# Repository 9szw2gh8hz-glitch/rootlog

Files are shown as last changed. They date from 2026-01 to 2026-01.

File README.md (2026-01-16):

# rootlog
## The Privacy-First, Local Data Logging Solution

RootLog is a dedicated environmental monitoring system designed to put data ownership back into the hands of the user. Unlike cloud-based smart home sensors, RootLog operates 100% locally. It monitors ambient conditions and air quality, storing every data point on a MicroSD card for private analysis.
Project Description

    Privacy-Focused: No Wi-Fi required; no data ever leaves the device.

    Robust Logging: Saves data to a MicroSD card every 60 seconds.

    Data Integrity: Features a "Flush" strategy that physically saves data to the card every 5 minutes to prevent loss during power failure.

    Power Management: Supports a Deep Sleep mode (activated by a 2-second button hold) to conserve battery during portable use.

    Multi-View Display: A 0.91" OLED screen cycles through 4 distinct data pages with a single tap.

## BOM

    Microcontroller: ESP32-C3 SuperMini

    Environmental Sensor: BME280 (Temp, Hum, Pres)

    Air Quality Sensor: SGP30 (eCO2, TVOC)

    Real-Time Clock: DS3231 RTC

    Display: 0.91" I2C OLED (128x32)

    Storage: MicroSD Card Module

## Wiring Map

Component	Pin Function	ESP32-C3 Pin
I2C Bus	SDA	GPIO 8
I2C Bus	SCL	GPIO 9
MicroSD	CS (Chip Select)	GPIO 7
MicroSD	MOSI	GPIO 6
MicroSD	MISO	GPIO 5
MicroSD	SCK (Clock)	GPIO 4
Control	Push Button	GPIO 2
Software & Setup
Required Libraries

## Usage Instructions

    Boot: Upon power-up, the OLED will display "ROOTLOG BOOTING..." while initializing sensors.

    Cycle Pages: Short-press the button to cycle between:

        Temperature (°C)

        Humidity (%) and Pressure (hPa)

        Air Quality (eCO2 ppm and TVOC ppb)

        Current System Time

    Power Off: Hold the button for 2 seconds. The screen will show "BYE BYE" and enter deep sleep.

    Wake Up: Press the button again to resume logging.

    Note on Calibration: The SGP30 air quality sensor requires approximately 15 seconds of operation to stabilize its internal baseline before reporting accurate eCO2 and TVOC values.

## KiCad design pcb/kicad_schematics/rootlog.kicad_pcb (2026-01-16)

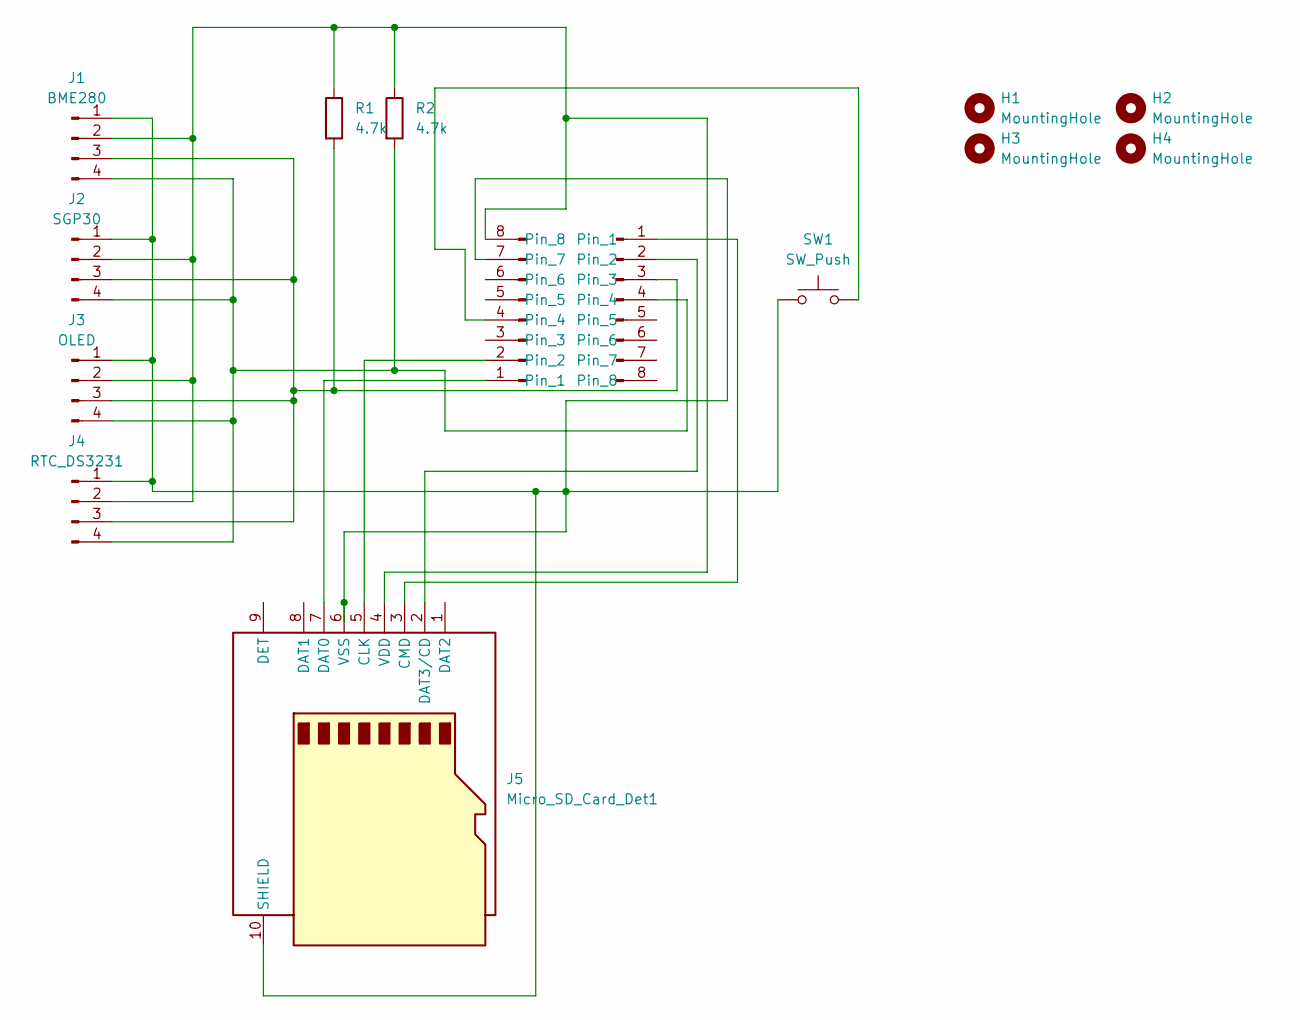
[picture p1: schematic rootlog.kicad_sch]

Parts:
H1, H2, H3, H4: MountingHole; MountingHole_3.2mm_M3
J1: BME280; FanPinHeader_1x04_P2.54mm_Vertical
J2: SGP30; FanPinHeader_1x04_P2.54mm_Vertical
J3: OLED; FanPinHeader_1x04_P2.54mm_Vertical
J4: RTC_DS3231; FanPinHeader_1x04_P2.54mm_Vertical
J5: Micro_SD_Card_Det1; microSD_HC_Hirose_DM3D-SF
J6, J7: Conn_01x08_Pin; PinHeader_1x08_P2.54mm_Vertical
R1, R2: 4.7k; R_Axial_DIN0207_L6.3mm_D2.5mm_P2.54mm_Vertical
SW1: SW_Push; SW_PUSH_6mm_H4.3mm

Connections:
unnamed: J1.1, J2.1, J3.1, J4.1, J5.6 (VSS), J5.10 (SHIELD), J6.7, SW1.1
unnamed: J1.2, J2.2, J3.2, J4.2, J5.4 (VDD), J6.8, R1.1, R2.1
unnamed: J1.3, J2.3, J3.3, J4.3, J7.3, R1.2
unnamed: J1.4, J2.4, J3.4, J4.4, J7.4, R2.2
unnamed: J5.5 (CLK), J6.2
unnamed: J5.3 (CMD), J7.1
unnamed: J5.7 (DAT0), J6.1
unnamed: J5.2 (DAT3/CD), J7.2
unnamed: J6.4, SW1.2

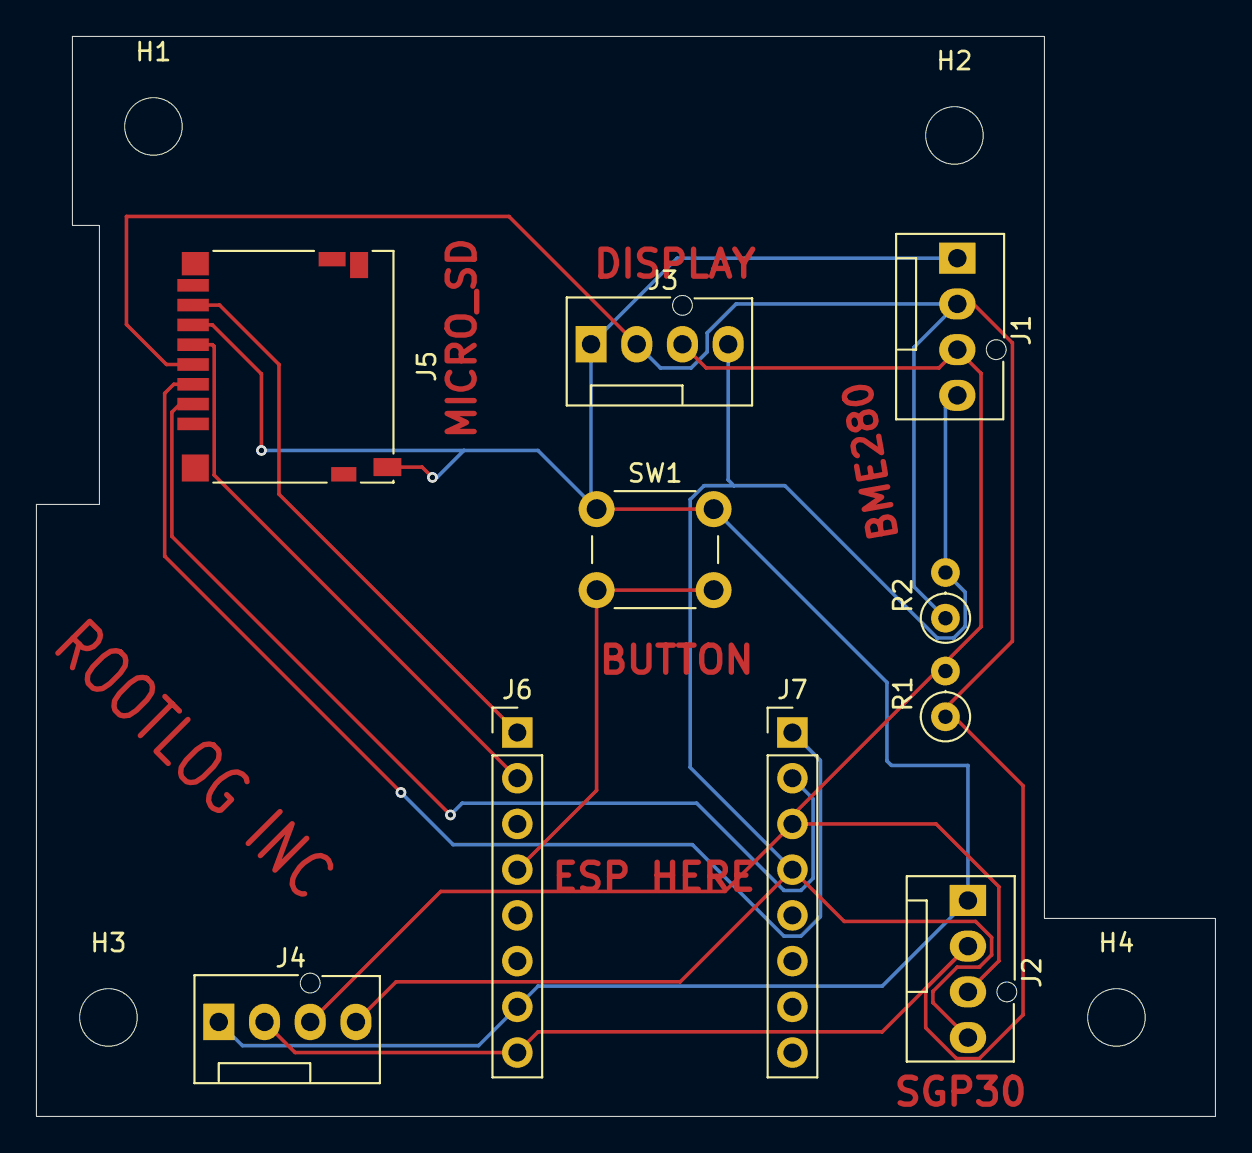
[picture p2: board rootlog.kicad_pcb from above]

Board: 2 copper layers, 65.5 x 60.0 mm, 14 parts (0 on the bottom side), 9 nets.

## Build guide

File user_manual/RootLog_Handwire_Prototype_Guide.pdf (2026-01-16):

RootLog Inc. — Built by hand. Powered by data.

# RootLog Handwire Assembly Guide

Prototype Edition — Point-to-Point Wiring

This guide covers manual assembly of the RootLog using perfboard and hand wiring. It is intended for prototype validation and one-off builds before custom PCB availability.

## Bill of Materials

1 ESP32-C3 SuperMini Microcontroller
2 Perfboard / Prototyping Board (≈4×6 cm)

3 BME280 Sensor Module

4 SGP30 Air Quality Sensor

5 DS3231 RTC Module

6 0.91" OLED Display (I2C)

7 MicroSD Card Module (SPI)

8 Push Button (Tactile)
9 2 × 4.7 kΩ Resistors (I2C Pull-ups)

10 22–24 AWG Solid Core Wire (Color-coded)

## Master Wiring Map

All connections follow a shared Power Bus (3.3 V), Ground Bus, I2C Data Bus, and a dedicated SPI bus for the MicroSD card. GPIO assignments must match firmware configuration.

## Assembly Phases

Phase 1 — Placement: Position the ESP32 near the USB edge. Keep the BME280 distant from the ESP32 to minimize heat influence.
Phase 2 — Power Bus: Create shared 3.3 V and GND rails. Verify continuity across all modules. Phase 3 — I2C Bus: Daisy-chain SDA and SCL, then add 4.7 kΩ pull-up resistors to 3.3 V.
Phase 4 — SPI (MicroSD): Wire CS, MOSI, MISO, and SCK directly to the ESP32 with short leads. Phase 5 — Button: Connect GPIO 2 to GND using the tactile switch; rely on internal pull-up.

## Final Verification & Power-Up

Before applying power, perform continuity checks between 3.3 V and GND. Any short must be corrected before connecting USB. A stable ESP32 LED indicates a safe power state.

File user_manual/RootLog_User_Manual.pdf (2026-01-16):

RootLog Inc. — Privacy First. Data Always.

# RootLog Owner’s Manual

Private Environmental Logger

Welcome to RootLog. You now own a dedicated, privacy■focused environmental monitor. Unlike smart home devices that send your data to the cloud, RootLog keeps everything local. All measurements are stored securely on a MicroSD card for your eyes only.

## What RootLog Monitors

1 Temperature (°C): Precision thermal monitoring.

2 Humidity (%): Relative humidity for comfort and mold prevention.

3 Pressure (hPa): Barometric pressure readings.

4 Air Quality (eCO2 & TVOC): Indicates when ventilation is recommended.

## Getting Started

Step 1: MicroSD Card
Format a MicroSD card to FAT32 and insert it into the slot. Ensure it is fully seated before powering the device.
Step 2: Power Up
Connect a USB■C cable to a 5V power source. During boot, the display will show system status. If 'SD Fail!' appears, recheck card formatting and insertion.

## Using RootLog

Display
The OLED shows live environmental data. Depending on firmware, the screen may dim automatically to extend lifespan.
Button Control

1 Short Press: Cycle through data screens.

2 Long Press (2s): Enter Deep Sleep mode. Press again to wake.

## Data Analysis

Each day is saved as a CSV file named by date (DD■MM■YYYY). Files can be opened with Excel, Google Sheets, or similar software to visualize trends over time.

## Specifications & Safety

1 Input Power: 5V USB■C (500 mA minimum).

RootLog Inc. — Privacy First. Data Always.

2 Operating Temperature: 0°C – 50°C.

3 Storage: MicroSD up to 32 GB.

4 Warning: Device is not waterproof. Avoid high■condensation environments.

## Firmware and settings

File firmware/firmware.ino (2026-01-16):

#include <Wire.h>
#include <SPI.h>
#include <SD.h>
#include <Adafruit_Sensor.h>
#include <Adafruit_BME280.h>
#include "Adafruit_SGP30.h"
#include "RTClib.h"
#include <Adafruit_GFX.h>
#include <Adafruit_SSD1306.h>

// --- PIN DEFINITIONS (Matched to your Schematic) ---
#define PIN_I2C_SDA     8   //
#define PIN_I2C_SCL     9   //
#define PIN_SD_CS       7   //
#define PIN_SD_MOSI     6   //
#define PIN_SD_MISO     5   //
#define PIN_SD_SCK      4   //
#define PIN_BUTTON      2   //

// --- SETTINGS ---
#define SCREEN_WIDTH    128
#define SCREEN_HEIGHT   32   
#define LOG_INTERVAL    60000 // Log every 1 minute (60,000ms)
#define FLUSH_COUNT     5     // Physically save to SD every 5 logs to save power/card life
#define LONG_PRESS_MS   2000  // 2 seconds to enter Deep Sleep

// --- OBJECTS ---
Adafruit_BME280 bme;
Adafruit_SGP30 sgp;
RTC_DS3231 rtc;
Adafruit_SSD1306 display(SCREEN_WIDTH, SCREEN_HEIGHT, &Wire, -1);

// --- GLOBAL VARIABLES ---
unsigned long lastLogTime = 0;
unsigned long buttonPressTime = 0;
int displayPage = 0; // 0=Temp, 1=Hum/Pres, 2=Air Quality, 3=Time
int logsSinceFlush = 0;
bool isButtonPressed = false;

// --- POWER OFF FUNCTION ---
void powerOff() {
  display.clearDisplay();
  display.setCursor(20, 10);
  display.setTextSize(2);
  display.println("BYE BYE");
  display.display();
  delay(1500);
  
  display.ssd1306_command(SSD1306_DISPLAYOFF);
  
  // Configure the button (Pin 2) to wake the device back up
  esp_sleep_enable_ext0_wakeup(GPIO_NUM_2, 0); 
  esp_deep_sleep_start();
}

void setup() {
  Serial.begin(115200);
  pinMode(PIN_BUTTON, INPUT_PULLUP);
  
  // Start I2C with your SuperMini pins
  Wire.begin(PIN_I2C_SDA, PIN_I2C_SCL);

  // Initialize OLED
  if(!display.begin(SSD1306_SWITCHCAPVCC, 0x3C)) {
    Serial.println("OLED Failed");
  }
  display.clearDisplay();
  display.setTextColor(SSD1306_WHITE);
  display.setCursor(0,0);
  display.println("ROOTLOG BOOTING...");
  display.display();

  // Initialize Sensors
  if (!bme.begin(0x76, &Wire)) Serial.println("BME280 Error");
  if (!sgp.begin(&Wire)) Serial.println("SGP30 Error");
  if (!rtc.begin(&Wire)) Serial.println("RTC Error");

  // Initialize SD Card
  SPI.begin(PIN_SD_SCK, PIN_SD_MISO, PIN_SD_MOSI, PIN_SD_CS);
  if (!SD.begin(PIN_SD_CS)) {
    display.println("SD CARD FAIL!");
    display.display();
  } else {
    display.println("SD CARD READY");
    display.display();
  }
  delay(1000);
}

void loop() {
  // 1. BUTTON LOGIC (Short press = Page, Long press = Off)
  int buttonState = digitalRead(PIN_BUTTON);
  
  if (buttonState == LOW && !isButtonPressed) {
    buttonPressTime = millis();
    isButtonPressed = true;
  } 
  else if (buttonState == HIGH && isButtonPressed) {
    unsigned long duration = millis() - buttonPressTime;
    if (duration > LONG_PRESS_MS) {
      powerOff();
    } else {
      displayPage++;
      if (displayPage > 3) displayPage = 0;
    }
    isButtonPressed = false;
  }

  // 2. SENSOR READING & LOGGING (Every 1 Minute)
  if (millis() - lastLogTime >= LOG_INTERVAL) {
    lastLogTime = millis();
    
    DateTime now = rtc.now();
    File dataFile = SD.open("/RootLog.csv", FILE_APPEND);
    
    if (dataFile) {
      // If file is new, add headers
      if (dataFile.size() == 0) {
        dataFile.println("Time,Temp,Hum,Pres,eCO2,TVOC");
      }
      
      // Write data row
      dataFile.print(now.timestamp()); dataFile.print(",");
      dataFile.print(bme.readTemperature()); dataFile.print(",");
      dataFile.print(bme.readHumidity()); dataFile.print(",");
      dataFile.print(bme.readPressure() / 100.0); dataFile.print(",");
      dataFile.print(sgp.eCO2); dataFile.print(",");
      dataFile.println(sgp.TVOC);

      // Flush strategy: Only force save every 5 minutes to protect the card
      logsSinceFlush++;
      if (logsSinceFlush >= FLUSH_COUNT) {
        dataFile.flush();
        logsSinceFlush = 0;
      }
      dataFile.close();
    }
  }

  // 3. AIR QUALITY BASELINE (Required by SGP30)
  sgp.IAQmeasure(); 

  // 4. DISPLAY UPDATE
  display.clearDisplay();
  display.setTextSize(1);
  display.setCursor(0, 0);
  display.print("ROOTLOG - PAGE "); display.println(displayPage + 1);
  display.drawLine(0, 9, 128, 9, WHITE);
  
  display.setCursor(0, 15);
  display.setTextSize(2);

  switch (displayPage) {
    case 0: // Temperature
      display.print(bme.readTemperature(), 1); display.print(" C");
      break;
    case 1: // Humidity & Pressure
      display.setTextSize(1);
      display.print("Hum: "); display.print(bme.readHumidity(), 0); display.println("%");
      display.print("Pre: "); display.print(bme.readPressure()/100, 0); display.print("hPa");
      break;
    case 2: // Air Quality
      display.setTextSize(1);
      display.print("eCO2: "); display.print(sgp.eCO2); display.println("ppm");
      display.print("TVOC: "); display.print(sgp.TVOC); display.print("ppb");
      break;
    case 3: // Time
      DateTime now = rtc.now();
      display.print(now.hour()); display.print(":"); 
      if(now.minute() < 10) display.print("0");
      display.print(now.minute());
      break;
  }
  display.display();
  delay(100); 
}
